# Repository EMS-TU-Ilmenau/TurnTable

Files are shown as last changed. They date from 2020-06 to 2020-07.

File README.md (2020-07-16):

# Turntable
Construction of a low-cost turntable positioner including 3D-printable parts and software to control it.

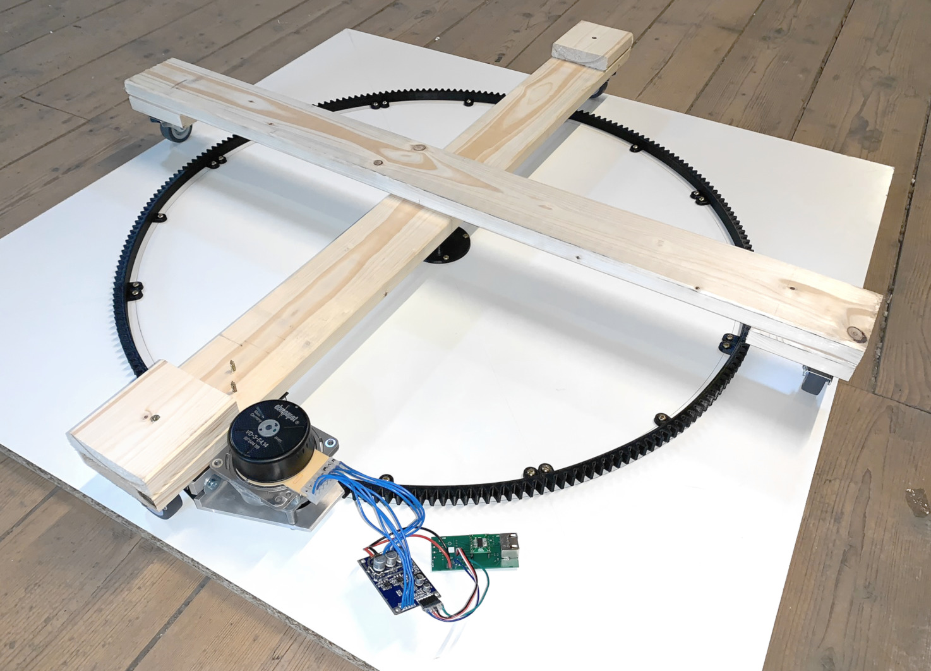
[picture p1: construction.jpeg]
Construction


## Construction
3D-printable parts and assembly can be found in the [construction](construction/) directory.

## Firmware
Quick-and-dirty mash-up of the [StepperDrive controller board](https://github.com/EMS-TU-Ilmenau/StepperDrive) and cheap e-Bike brushless motor controller (with hall sensor inputs), documented in the [firmware](firmware/) directory.

## Interface
Use the Python interface to talk to the firmware and do the steps to degree conversions in the [interface](interface/) directory.

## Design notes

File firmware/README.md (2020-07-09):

# TurnTableDrive
Firmware to control the motor

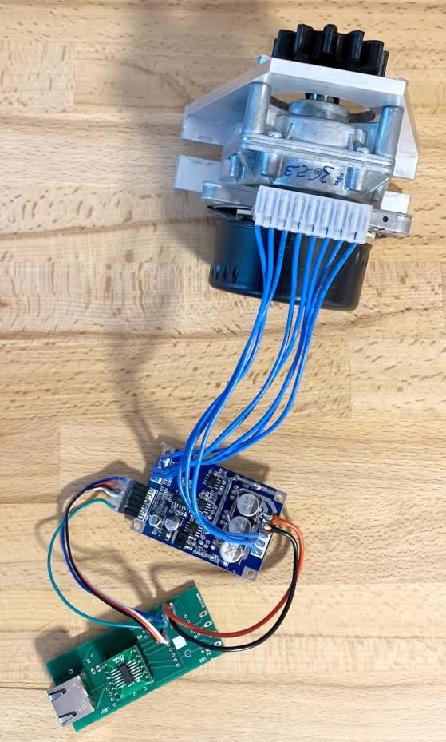
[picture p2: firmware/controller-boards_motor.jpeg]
Controller-boards


This is basically a quick-and-dirty mash-up of the [StepperDrive controller board](https://github.com/EMS-TU-Ilmenau/StepperDrive) and cheap e-Bike brushless motor controller (with hall sensor inputs) which takes an analog level as input for speed and outputs a tacho pulse TTL signal.

This firmware is very basic. It just counts the tacho pulses to get the step position (12 changing edges per rotor revolution * 38.6 motor gear ratio * 20 table gear ratio = 9264 steps per table revolution) and generates a high frequency PWM (that is filtered by the RC lowpass on the brushless motor controller board) to adjust speed.

## Getting started
The firmware uses the same hardware and baudrate as the [StepperDrive controller board](https://github.com/EMS-TU-Ilmenau/StepperDrive). That means it can be connected to the hub board as well. Depending on the used motor, the 12V power supply on the hub may be replaced by something more powerful.

### Commands
The following SCPI-like commands can be used with the firmware (see StepperDrive for more details):
- `AXn:VEL [speed]`: where speed can be -1000...1000 to set a relative motor power and direction
- `AXn:POS?`: requests the current step position (accumulated tacho pulses)
- `AXn:POS [defined step position]`: sets the accumulated tacho pulses to a new value, i.e. the current step position is redefined. **This does NOT drive to a certain position**
- `AXn:PER?`: requests the last period between two steps in us, divided by 128. So the response must be multiplied by 128 to get the period in microseconds. **Note:** when the motor is at very slow speed or it stops, this value gets crazy due to overflow.

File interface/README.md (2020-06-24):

# TurnTableControl
Python interface for the turntable controller board

## Getting started
Install this package via `pip install .`

**Example**
```python
from turntablecontrol import TurnTableControl

table = TurnTableControl('COM7', axisID=6)
table.setSpeed(500) # power control -1000...1000
print(f'Current position: {table.position} deg, rate: {table.rate} deg/s')
```

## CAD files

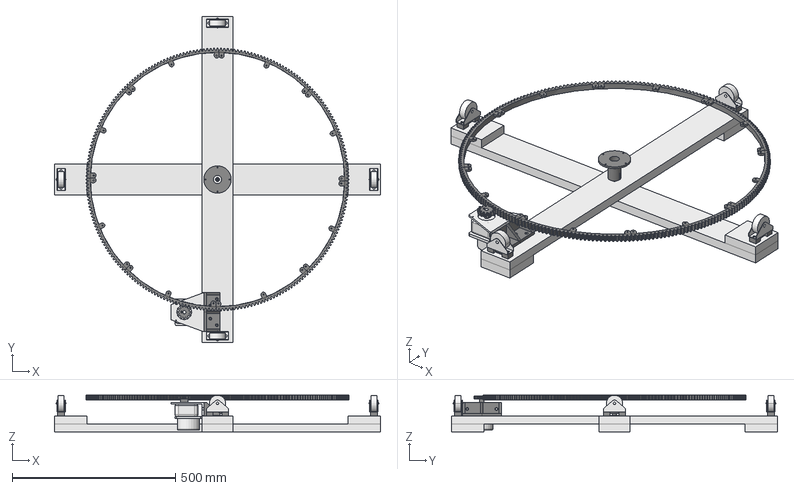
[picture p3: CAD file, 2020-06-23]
construction/Assembly.FCStd
1000.0 x 1000.0 x 112.0 mm
Stand_001
CastorWasher_001
CastorWasher_002
CastorWasher_003
CastorWasher_004
Castor_001
Castor_002
Castor_003
Castor_004
StandAxis_001
TableGearSegment_001
TableGearSegment_002
TableGearSegment_003
TableGearSegment_004
TableGearSegment_005
TableGearSegment_006
TableGearSegment_007
TableGearSegment_008
TableAxisMount_001
MotorMount_001
Motor_001
MotorGear_001

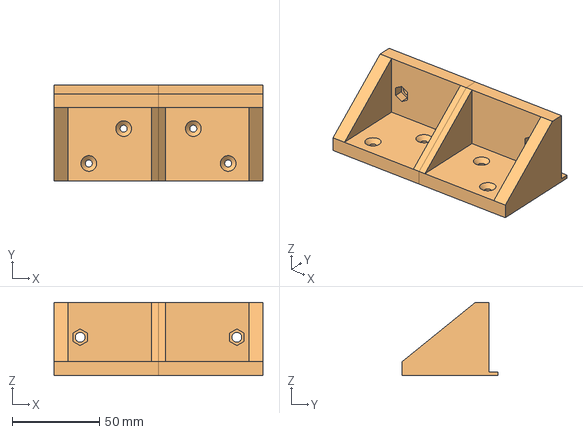
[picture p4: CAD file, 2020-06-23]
construction/MotorMount.FCStd
120.0 x 55.0 x 42.0 mm
MotorMount

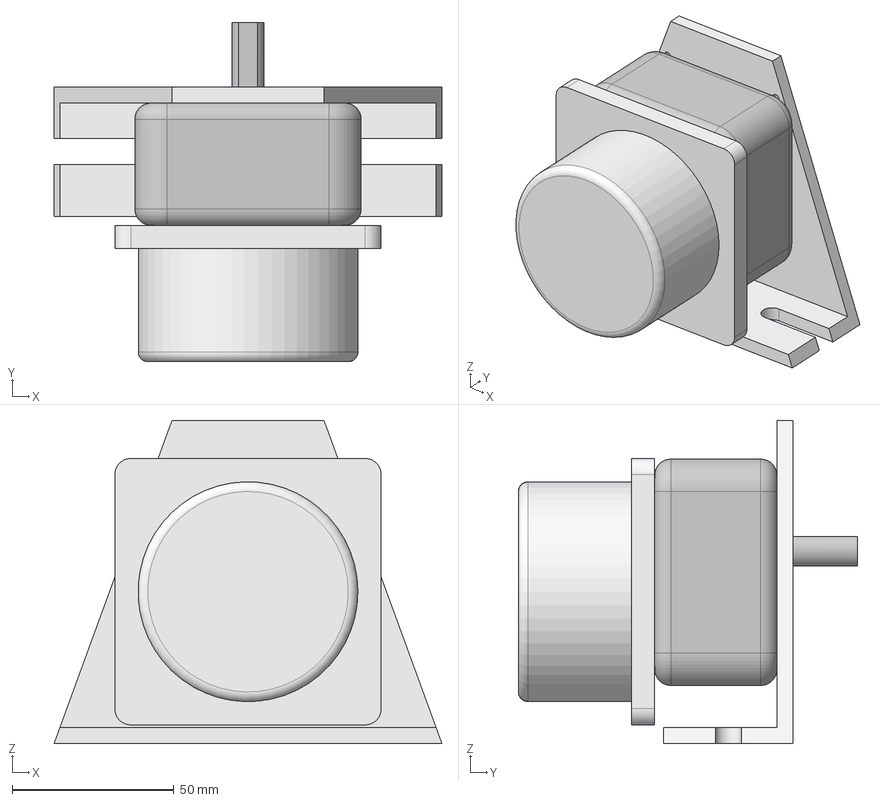
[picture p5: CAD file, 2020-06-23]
construction/Motor.FCStd
120.0 x 105.0 x 100.0 mm
LStand
Gearbox
Stator
Rotor

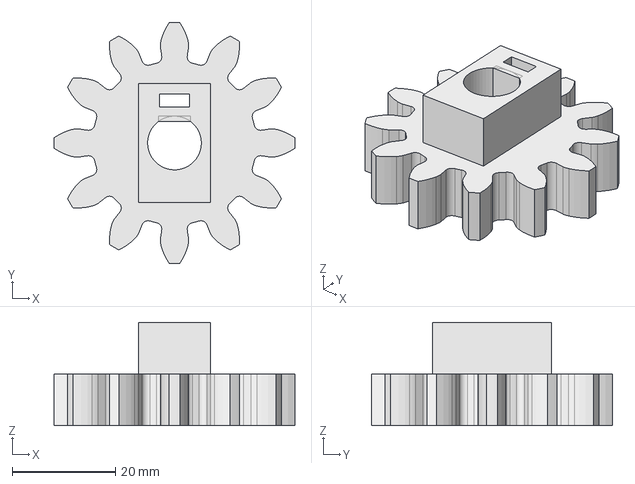
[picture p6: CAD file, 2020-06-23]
construction/MotorGear.FCStd
46.6 x 46.6 x 20.0 mm

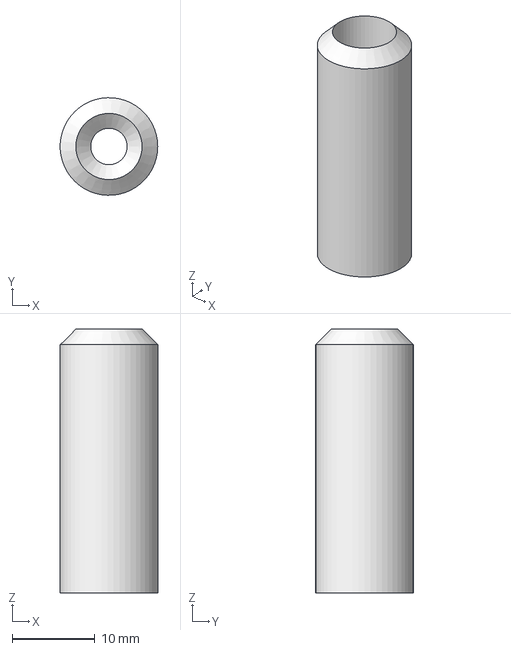
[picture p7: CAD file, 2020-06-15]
construction/StandAxis.FCStd
11.8 x 11.8 x 31.9 mm

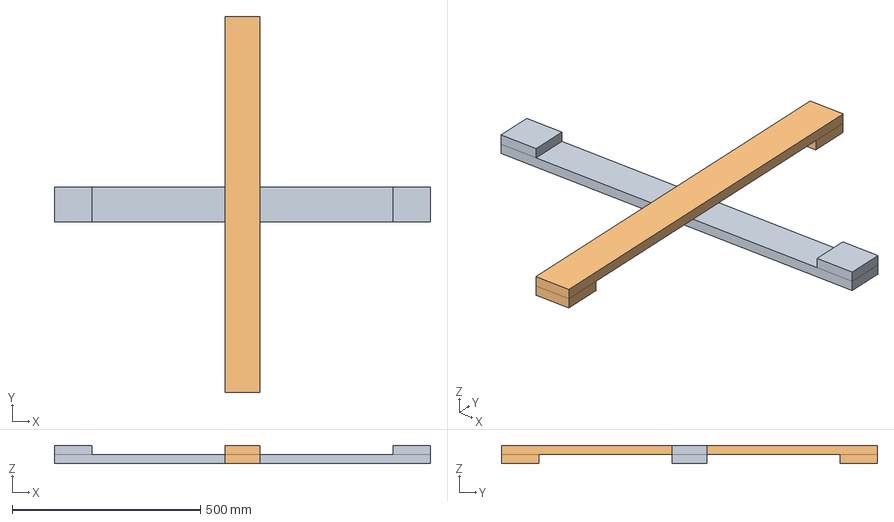
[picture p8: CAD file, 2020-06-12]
construction/Stand.FCStd
1000.0 x 1000.0 x 48.0 mm
Stand
StandTop

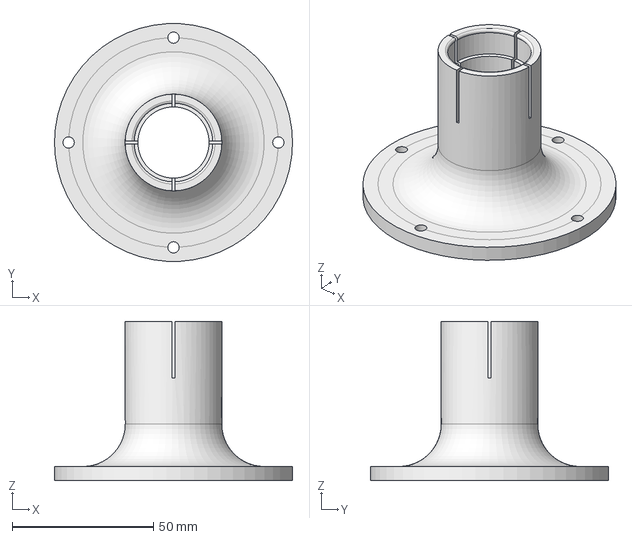
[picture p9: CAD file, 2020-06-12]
construction/TableAxisMount.FCStd
84.2 x 84.1 x 56.3 mm

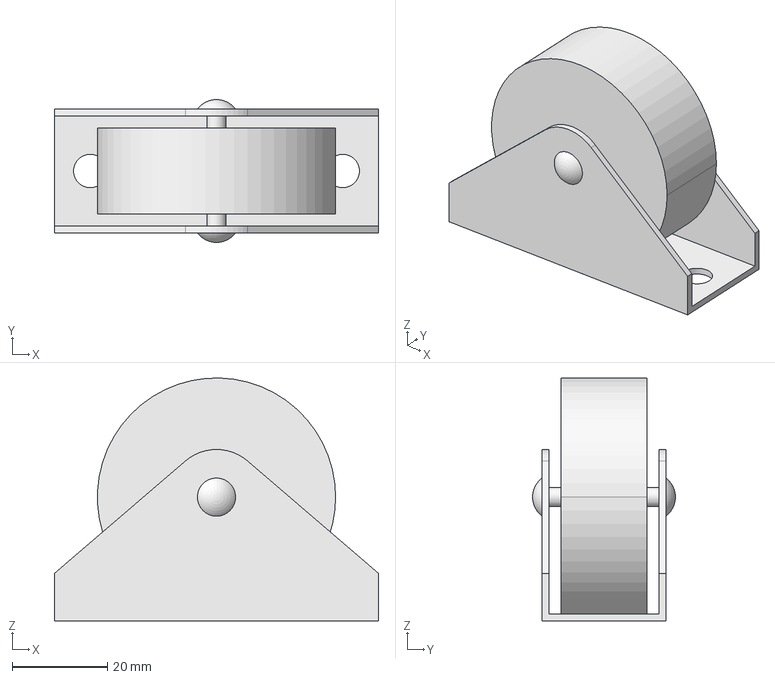
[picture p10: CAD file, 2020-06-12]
construction/Castor.FCStd
68.0 x 30.0 x 51.0 mm

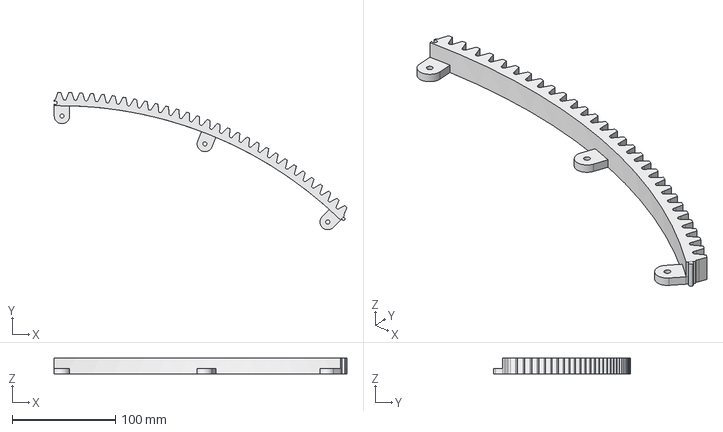
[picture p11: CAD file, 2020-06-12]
construction/TableGearSegment.FCStd
283.5 x 133.0 x 15.0 mm

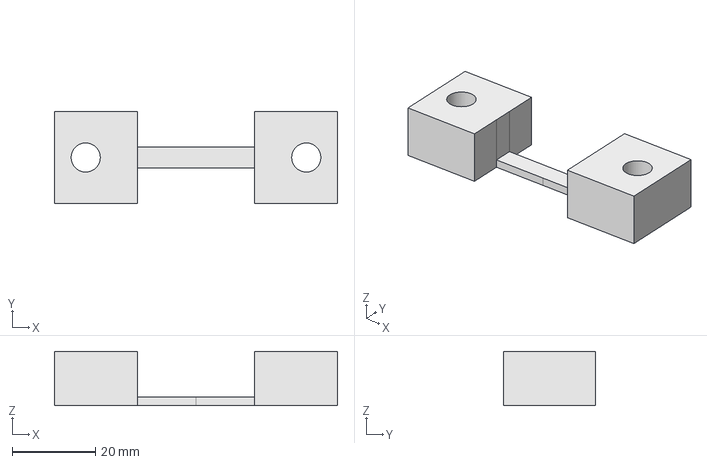
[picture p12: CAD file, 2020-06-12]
construction/CastorWasher.FCStd
68.0 x 22.0 x 13.0 mm

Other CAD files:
construction/CastorWasher.stl
construction/MotorGear.stl
construction/MotorMount.stl
construction/StandAxis.stl
construction/TableAxisMount.stl
construction/TableGearSegment.stl

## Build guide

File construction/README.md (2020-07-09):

# Construction
The individual parts are made using FreeCAD. They are available as .stl files to be 3D-printed. The assembly was made poorly using the A2plus workbench, which can be installed via the Addon-Manager.

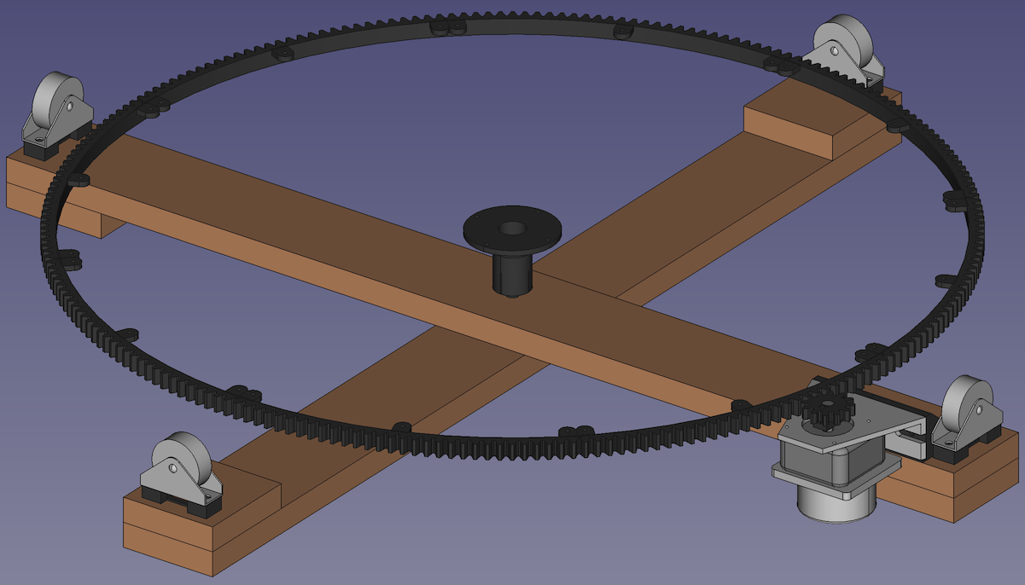
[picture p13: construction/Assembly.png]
Assembly


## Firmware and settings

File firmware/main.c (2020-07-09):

#include <avr/io.h> // for pin definitions
#include <stdint.h> // for shorter types
#include <avr/interrupt.h> // for sei(), cli() and ISR()
#include <string.h>	// for string operations like cmp and cat
#include <stdlib.h>	// for string to number conversion
#include "main.h" // for main setup


ISR(TIMER2_CAPT_vect) {
	// interrupt for timer2 input capture
	curStepPeriod = ICR2; // capture timer counter value
	TCNT2 = 0; // reset timer counter
	TCCR2B ^= (1 << ICES2); // toggle trigger edge
	if (tarStepVel > 0) curStepPos++;
	if (tarStepVel < 0) curStepPos--;
}

int main() {
	// configurations
	configGPIO();
	configUSART0();
	configTimer1();
	configTimer2();
	// activating interrupts
	sei();
	while(1) {
		receiveUSARTChar();
		if (gotCommand) {
			gotCommand = FALSE;
			parseCommand((char*)(uartReceiveStr));
		}
	}
	return 0;
}

inline void receiveUSARTChar() {
	// collect newly arrived bytes
	if (!(UCSR0A & (1 << RXC0))) return; // no new char received yet
	// new char available
	char nextChar = UDR0;
	if (nextChar != STR_TERM && uartStrCount < UART_MAXSTRLEN) {
		// still getting valid chars
		uartReceiveStr[uartStrCount++] = nextChar;
	} else {
		// end of string
		uartReceiveStr[uartStrCount] = STR_TERM;
	  	uartStrCount = 0;
		gotCommand = TRUE;
	}
}

inline void parseCommand(char* strP) {
	// search entry point: our axis with ID ("AX<ID>")
	char* cmdP = strstr(strP, CMD_ID);
	if (cmdP) {
		cmdP += 4; // skip "AX<ID>:"
		if (strncmp(cmdP, "VEL", 3) == 0) {
			// set speed (-1000...1000)
			cmdP += 3;
			tarStepVel = strtol(cmdP, NULL, RADIX);
			// set direction
			if (tarStepVel < 0) {
				PORTA |= (1 << DIR_PIN); // table backward
			} else {
				PORTA &= ~(1 << DIR_PIN); // table forward
			}
			// set pwm
			OCR1B = (uint16_t)(abs(tarStepVel));
		} else if (strncmp(cmdP, "POS", 3) == 0) {
			// current position
			cmdP += 3;
			if (*cmdP == '?') {
				ltoa(curStepPos, uartSendStr, RADIX);
				sendUSARTString(uartSendStr);
			} else {
				curStepPos = strtol(cmdP, NULL, RADIX);
			}
		} else if (strncmp(cmdP, "PER?", 4) == 0) {
			// get current step period
			/* 
			NOTE: due to the prescaler of 1024 and the clock freq of 8 MHz, 
			the step period is in [us]/128. So multiply by 128 to get it in us.
			*/
			utoa(curStepPeriod, uartSendStr, RADIX);
			sendUSARTString(uartSendStr);
		} else {
			// no valid command
			strcpy(uartSendStr, "No valid command: ");
			strcat(uartSendStr, cmdP);
			sendUSARTString(uartSendStr);
		}
	} else {
		// no axis specific command
		cmdP = strstr(strP, "*IDN?");
		if (cmdP) {
			// requested for device name
			sendUSARTString(CMD_ID);
		}
	}
}

void configGPIO() {
	// configure pin i/o
	DDRA |= (1 << SPEED_PIN) | (1 << DIR_PIN); // output pins for direction and speed pwm
}

void configUSART0() {
	// set baud rate
	UBRR0H = (uint8_t)(UART_UBRR >> 8);
	UBRR0L = (uint8_t)UART_UBRR;
	// enable receiver and transmitter pins
	UCSR0B = (1 << RXEN0) | (1 << TXEN0);
	// frame format: 8N1 (is initially set anyway)
	UCSR0C = (1 << UCSZ01) | (1 << UCSZ00);
	// double speed because the error is too high (-7%) for baud 9600 without U2X
	UCSR0A = (1 << U2X0);
}

void configTimer1() {
	// configure 16 bit timer1 as Fast PWM mode 14, resolution set by ICR1, non-inverting
	TCCR1A = (1 << WGM11) | (1 << COM1B1);
	TCCR1B = (1 << WGM12) | (1 << WGM13) | (1 << CS11);
	// set top / resolution value / period
	ICR1 = MAX_PWM; // in us for F_CPU = 8MHz and prescale 8 (CS11)
	// enable channel output for TOCCx Pin
	TOCPMSA1 = (1 << TOCC6S0);
	TOCPMCOE = (1 << TOCC6OE);
	// initial duty cycle on-puls length (0...ICR1) in us
	OCR1B = 0;
}

void configTimer2() {
	// configure 16 bit timer2 as input capture to get the puls width
	TCCR2B = (1 << CS22) | (1 << CS20) | (1 << ICES2); // Prescaler 1024, trigger on rising edge
	TIMSK2 = (1 << ICIE2); // enable interrupt on input
}

void sendUSARTChar(const char c) {
	// wait for empty transmit buffer
	while (!(UCSR0A & (1 << UDRE0)));
	// put char into buffer
	UDR0 = c;
}

void sendUSARTString(const char* pStr) {
	// send all characters in string
	while(*pStr) {
		sendUSARTChar(*pStr);
		pStr++;
	}
	// append string termination
	sendUSARTChar(STR_TERM);
}

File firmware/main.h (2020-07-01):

#include <avr/io.h> // for pin definitions
#include <stdint.h> // for shorter types

// constant definitions
#define STR_HELPER(x) #x
#define STR(x) STR_HELPER(x)
#define FALSE 0
#define TRUE 1
#define UART_BAUD 9600UL
#define UART_UBRR (F_CPU/(8*UART_BAUD)-1) // calculate register value for baudrate for U2Xn = 1
#define UART_MAXSTRLEN 32
#define RADIX 10 // for itoa
#define CMD_ID "AX" STR(AX_ID) // axis specific commands must start with AX<id>
#define STR_TERM '\n'
#define TACHO_PIN PB2
#define SPEED_PIN PA7
#define DIR_PIN PA6
#define MAX_PWM 1000 // pwm period in us

// variables
uint8_t uartStrCount = 0;
uint8_t gotCommand = FALSE;
char uartReceiveStr[UART_MAXSTRLEN] = "";
char uartSendStr[UART_MAXSTRLEN] = "";
volatile int32_t curStepPos = 0;
volatile int16_t tarStepVel = 0;
volatile uint16_t curStepPeriod = 0;

// prototypes
void configGPIO();
void configUSART0();
void receiveUSARTChar();
void parseCommand(char* pCmd);
void sendUSARTChar(const char c);
void sendUSARTString(const char* pStr);
void configTimer1();
void configTimer2();

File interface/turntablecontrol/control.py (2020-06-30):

import serial # (pyserial) for communicating with the controller board
import time # for sleeping


class TurnTableControl:
    '''
    Class to control the TurnTable project board
    '''
    def __init__(self, port, axisID=6, startPos=None, rotorSteps=12, motorGearRatio=38.6, tableGearRatio=20):
        '''
        :param port: serial port to communicate with the motor controller
            OR already opened serial object
        :param axisID: motor controller board identifier number
        :param startPos: optional: redefine current physical position (angle) in degrees
        :param motorSteps: number of steps per rotor revolution
        :param motorGearRatio: ratio:1 of the motor gear
        :param tableGearRatio: ratio:1 of the table gear
        '''
        self.id = axisID
        self.rotorSteps = rotorSteps
        self.motorGearRatio = motorGearRatio
        self.tableGearRatio = tableGearRatio

        # connect
        self.dev = None
        if isinstance(port, serial.Serial):
            self.dev = port
        elif isinstance(port, str):
            self.connect(port)
        else:
            raise TypeError('port must be either a string or serial.Serial object')

        # initial settings
        if startPos is not None:
            self.position = startPos
    

    def __del__(self):
        # close connection properly when destructing the instance
        self.disconnect()
    

    def connect(self, port):
        '''
        Connect to serial port
        '''
        try:
            self.dev = serial.Serial(port, 9600, timeout=2)
        except:
            raise IOError('Cannot connect to stepper motor controller hub')
    

    def disconnect(self):
        '''
        Disconnect from serial port
        '''
        if self.dev:
            self.dev.close()
    

    def send(self, cmd):
        '''
        sends a command via the port to the motor controller

        :param cmd: command string (without line endings) to send
        :returns: when the command was a query, the response string is returned
        '''
        self.dev.write(bytes(cmd+'\n', 'ascii'))
        if '?' in cmd:
            resp = self.dev.readline()
            return str(bytes(filter(lambda c: c > 32, resp)), 'ascii') # remove control chars
        return None
    

    @property
    def axStr(self):
        '''
        :returns: complete axis name (prefix + id)
        '''
        return f'AX{self.id}'
    

    def setSpeed(self, speed):
        '''
        Sets the rotor power
        
        :param speed: number between -1000...1000
        '''
        self.send(f'{self.axStr}:VEL {speed}')
    

    @property
    def tableRevSteps(self):
        '''
        :returns: number of steps per table revolution
        '''
        return self.rotorSteps*self.motorGearRatio*self.tableGearRatio
    

    @property
    def position(self):
        '''
        :returns: current table angle in degrees
        '''
        rotorSteps = int(self.send(f'{self.axStr}:POS?'))
        # convert rotor step position to table position
        tablePos = 360*rotorSteps/self.tableRevSteps
        return tablePos
    

    @position.setter
    def position(self, val):
        '''
        Defines the current table angle in degrees
        '''
        # convert table position to rotor steps
        rotorSteps = int(round(val*self.tableRevSteps/360))
        # send to board
        self.send(f'{self.axStr}:POS {rotorSteps}')


    @property
    def rate(self):
        '''
        :returns: current table velocity in degrees/s
        '''
        stepPeriod = int(self.send(f'{self.axStr}:PER?'))*128 # in us
        if stepPeriod == 0:
            return -1
        stepPeriod *= 1e-6 # in s
        stepRate = 1/stepPeriod # in steps/s
        angleRate = 360*stepRate/self.tableRevSteps
        return angleRate

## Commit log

2020-06-12 added stand construction
    [Stand.FCStd]
2020-06-15 made StandAxis a bit thicker to better fit inside bearing
    [StandAxis.FCStd, StandAxis.stl]
2020-06-15 added assembly
    [Assembly.FCStd]
2020-06-16 adjusted motor shaft flatness length to match actual motor
    [Motor.FCStd]
2020-06-16 adjusted to fit on motor shaft with lower flatness length
    [MotorGear.FCStd, MotorGear.stl]
2020-06-16 motor mount is now a bit tighter
    [MotorMount.FCStd, MotorMount.stl]
2020-06-16 fixed motor gear fixation screw hole
    [MotorGear.FCStd, MotorGear.stl]
2020-06-23 Using a different motor now
    [Assembly.FCStd, Motor.FCStd, MotorGear.FCStd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]
2020-06-26 reversed speed/position because of the table gear
    [control.py]
2020-06-30 position, velocity and period should now be parsed and send with correct datatype length
    [main.c, main.h]
2020-06-30 reverted direction sign again and removed position modulo as direction was reversed and position datatype length increased in firmware
    [control.py]
2020-07-01 truly inverted direction behaviour
    [main.c]
2020-07-01 to reduce interrupts, USART chars are now received in main loop
2020-07-02 fixed direction pin setting
    [main.c]
